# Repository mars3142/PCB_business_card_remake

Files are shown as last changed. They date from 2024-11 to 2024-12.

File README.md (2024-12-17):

# PCB business card - StuckAtPrototype

A custom PCB based "business" card that lets you play a version of Flappy Bird. 

## Youtube Video
A bit of a back-story of how this project came to be.

My Kickstarter failed, so I open sourced it (https://youtu.be/y-lWarLUhfg)

Sub if you like what you see.

## Project Structure
The project consists of
1. Firmware
2. Hardware
3. Mechanical
4. Scripts

These are structured into their own files. I could have used submodules, but decided against it.

### 1. Firmware
Code for the business card. This lives on the ESP32

#### Requirements
- ESP32 IDF version 5.4
- Target set to ESP32-H2
- BLE configured to NIMBLE

### 2. Hardware

#### Schematic
PDF schematic included for your viewing pleasure.
#### PCBs
All the gerber files you'd need to send to a fab house.
#### Kicad
All the files you'd need to expand and work on this further. If you'd like.

### 3. Mechanical

#### Enclosure
All the step files you need to make one of these. Extrusion printer works well for this part.

### 4. Scripts

The script requires the `config.py` file to be modified. You will need to create your own API key at openweather.org

To run the script, simply run `python CardController.py`

#### Requirements
A bunch of pip packages

## What the project could use
1. Cleanup, but thats true for almost anything out there
2. A proper graphics library -- Adafruit, or even LVGL 
3. Scripts that would show stock data. anyone? 

## If you take it further
Let me know if you ever make one of these, I'd love to see it. Seriously, that'd be exciting and inspiring to keep making my projects open source!

## Known issues
1. Switch requires to be shorted due to power consumption at run time
2. GPIO 1 as is does not allow the device to wake up from sleep
3. The LEDs seem to be pulling a lot power even when ESP32 is in deep sleep mode

---
## License
### Apache 2.0 -- i.e. use as you'd like
http://www.apache.org/licenses/LICENSE-2.0

--- 
## Special Thanks
Thanks to Michael Angerer for his open sourced `esp32_ble_ota` project. I used it to get BLE running in this project. His blog post and github repo are a great resource. Check it out. https://github.com/michael-angerer/esp32_ble_ota

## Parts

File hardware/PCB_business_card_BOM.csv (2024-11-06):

Id | Designator | Footprint | Quantity | Designation | Supplier and ref | Notes
1 | LED16,LED107,LED49,LED64,LED59,LED106,LED6,LED3,LED36,LED34,LED15,LED109,LED4,LED74,LED82,LED47,LED28,LED73,LED75,LED20,LED81,LED90,LED19,LED8,LED44,LED58,LED35,LED72,LED17,LED61,LED12,LED63,LED48,LED116,LED29,LED93,LED96,LED102,LED5,LED51,LED18,LED7,LED39,LED53,LED56,LED37,LED95,LED31,LED62,LED42,LED98,LED117,LED43,LED60,LED57,LED45,LED24,LED23,LED79,LED97,LED105,LED27,LED112,LED89,LED25,LED70,LED54,LED50,LED120,LED100,LED68,LED119,LED30,LED66,LED88,LED76,LED80,LED21,LED110,LED11,LED33,LED41,LED94,LED2,LED103,LED78,LED1,LED9,LED38,LED87,LED114,LED115,LED32,LED67,LED10,LED111,LED108,LED104,LED26,LED52,LED69,LED86,LED84,LED22,LED13,LED40,LED14,LED85,LED83,LED101,LED46,LED91,LED55,LED77,LED113,LED118,LED71,LED99,LED92,LED65 | IN-PI15_INL | 120 | IN-PI15TAT5R5G5B | IN-PI15TAT5R5G5B
3 | S4,S2,S3 | SW_PTS810_SJM_250_SMTR_LFS | 3 | SW_PTS810_SJM_250_SMTR_LFS | PTS810 SJM 250 SMTR LFS
4 | C114,C51,C33,C105,C24,C129,C92,C32,C96,C55,C6,C62,C81,C36,C17,C74,C64,C116,C103,C100,C59,C30,C61,C27,C25,C124,C7,C34,C26,C118,C37,C120,C108,C69,C9,C71,C63,C88,C52,C49,C20,C125,C40,C47,C99,C72,C53,C94,C107,C41,C57,C68,C14,C75,C106,C87,C45,C82,C48,C104,C78,C43,C35,C113,C122,C58,C101,C28,C119,C89,C46,C110,C76,C98,C67,C31,C39,C112,C54,C44,C19,C38,C22,C86,C97,C130,C102,C80,C18,C91,C128,C23,C93,C131,C115,C50,C111,C77,C21,C123,C83,C60,C13,C84,C85,C79,C12,C11,C70,C127,C15,C126,C109,C56,C42,C95,C73,C132,C65,C90,C29,C16,C66,C121 | C_0603_1608Metric | 124 | 0.1uF | CC0603KRX7R7BB104
5 | R5,R6 | R_0603_1608Metric | 2 | 5k1 | RMCF0603JT5R10
6 | R16,R17,R28,R27,R11,R10,R19 | R_0603_1608Metric | 7 | 10k | WR06X103 JTL
7 | C2,C135,C10,C133,C3,C1 | C_0603_1608Metric | 6 | 10uF | GRM188R61A106ME69D
8 | U1 | TPS631000DRLR_TEX | 1 | TPS631000DRLR | TPS631000DRLR
9 | D1 | D_0603_1608Metric | 1 | PWLED | 150060RS75000
10 | R14,R20 | R_0603_1608Metric | 2 | 100k | WR06X1003FTL
11 | C8,C117 | C_0603_1608Metric | 2 | 1uF 25V | CC0603KRX5R8BB105
12 | R3 | R_0603_1608Metric | 1 | 75K | ERJ-PB3B7502V
13 | R23 | R_0603_1608Metric | 1 | 0 |  | NOTE: solder jump
14 | D4 | D_0603_1608Metric | 1 | LED | 150060GS75000 | NOTE: might be mixed up with D3
15 | D3 | D_0603_1608Metric | 1 | LED | 150060RS75000 | NOTE: might be mixed up with D4
16 | TH1 | R_0603_1608Metric | 1 | TH 10k | NTCG163JF103HT1
17 | Q3 | SOT-23 | 1 | BSS138 | BSS138
18 | U2 | SON50P300X300X100-11N | 1 | MCP73833 | MCP73833T-AMI/MF
19 | S1 | SW_JS102011SAQN | 1 | JS102011SAQN | JS102011SAQN
20 | C5 | C_0603_1608Metric | 1 | 47uF | GRM188C80E476ME05D
21 | C4 | C_0603_1608Metric | 1 | 22uF | GRM188R60J226MEA0J
22 | R15,R18 | R_0603_1608Metric | 2 | 10K | WR06X103 JTL | NOTE: combine with above
23 | R21,R12,R22 | R_0603_1608Metric | 3 | 470 | ESR03EZPF4700
25 | R7 | R_0603_1608Metric | 1 | 1M | RMCF0603FT1M00
26 | L1 | RES_CIGT252010 | 1 | 1uH | CIGT252010EH1R0MNE
27 | P1 | GCT_USB4105-GF-A | 1 | USB_C_Plug_USB2.0 | USB4105-GF-A
28 | U5 | AP2204 | 1 | AP2204 | AP2205-33W5-7 | NOTE: changed for AP2205
29 | R1 | R_0603_1608Metric | 1 | 806 | RQ73C1J806RBTDF
31 | R2 | R_0603_1608Metric | 1 | 1.43K | RT0603BRE071K43L
32 | R8,R9 | R_0603_1608Metric | 2 | 200 |  | NOTE: change to 470
33 | D5 | D_SMA | 1 | D_Schottky 1A | MBRA210LT3G | NOTE: changed to 2A diode
34 | Q1 | SOT-23-DMG2301 | 1 | Q_PMOS_SGD | DMG2301L-7
35 | C134 | C_0603_1608Metric | 1 | 2.2uF | CL10A225KO8NNNC
36 | J3 | JST_PH_S2B-PH-SM4-TB_1x02-1MP_P2.00mm_Horizontal | 1 | JST 2.0 BATT | S2B-PH-SM4-TB
37 | R13 | R_0603_1608Metric | 1 | 91 | CR0603-FX-91R0ELF
38 | U3 | MODULE_ESP32-H2-MINI-1-H2 | 1 | ESP32-H2-MINI-1 | ESP32-H2-MINI-1
39 | U4 | A3908 | 1 | A3908 | A3908EEETR-T
40 | D2 | D_SOD-523 | 1 | TPD1E10B06DPYR | TPD1E10B06DYAR
41 | R4 | R_0603_1608Metric | 1 | 5K1 | RMCF0603JT5R10 | NOTE: combine with above

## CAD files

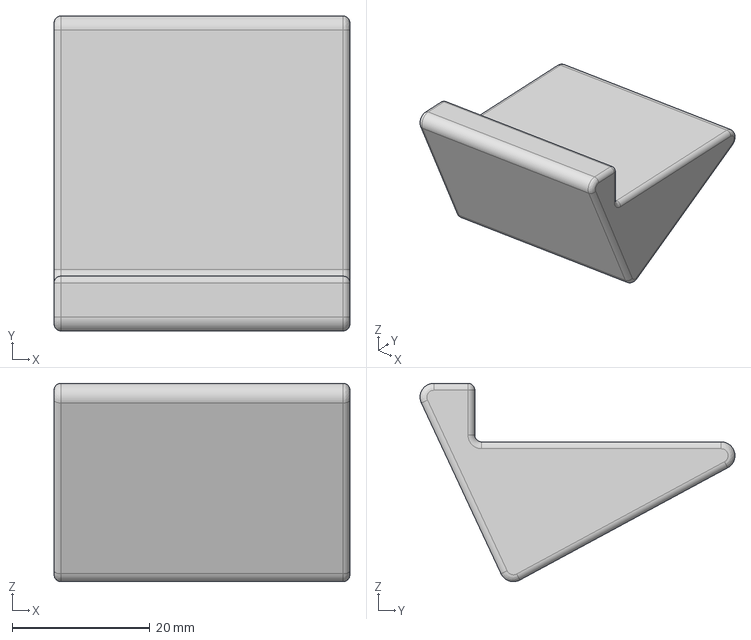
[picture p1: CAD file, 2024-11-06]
mechanical/PCB business card enclosure stand.step
43.0 x 45.8 x 28.8 mm

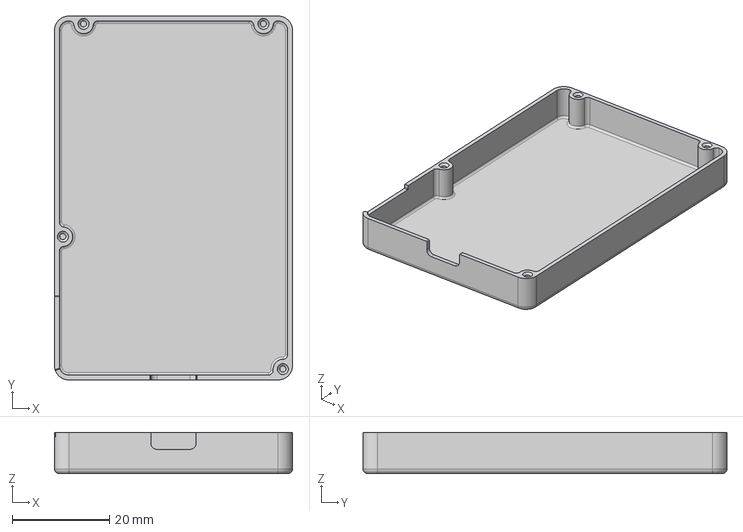
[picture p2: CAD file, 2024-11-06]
mechanical/PCB business card enclosure.step
49.0 x 74.9 x 8.50 mm

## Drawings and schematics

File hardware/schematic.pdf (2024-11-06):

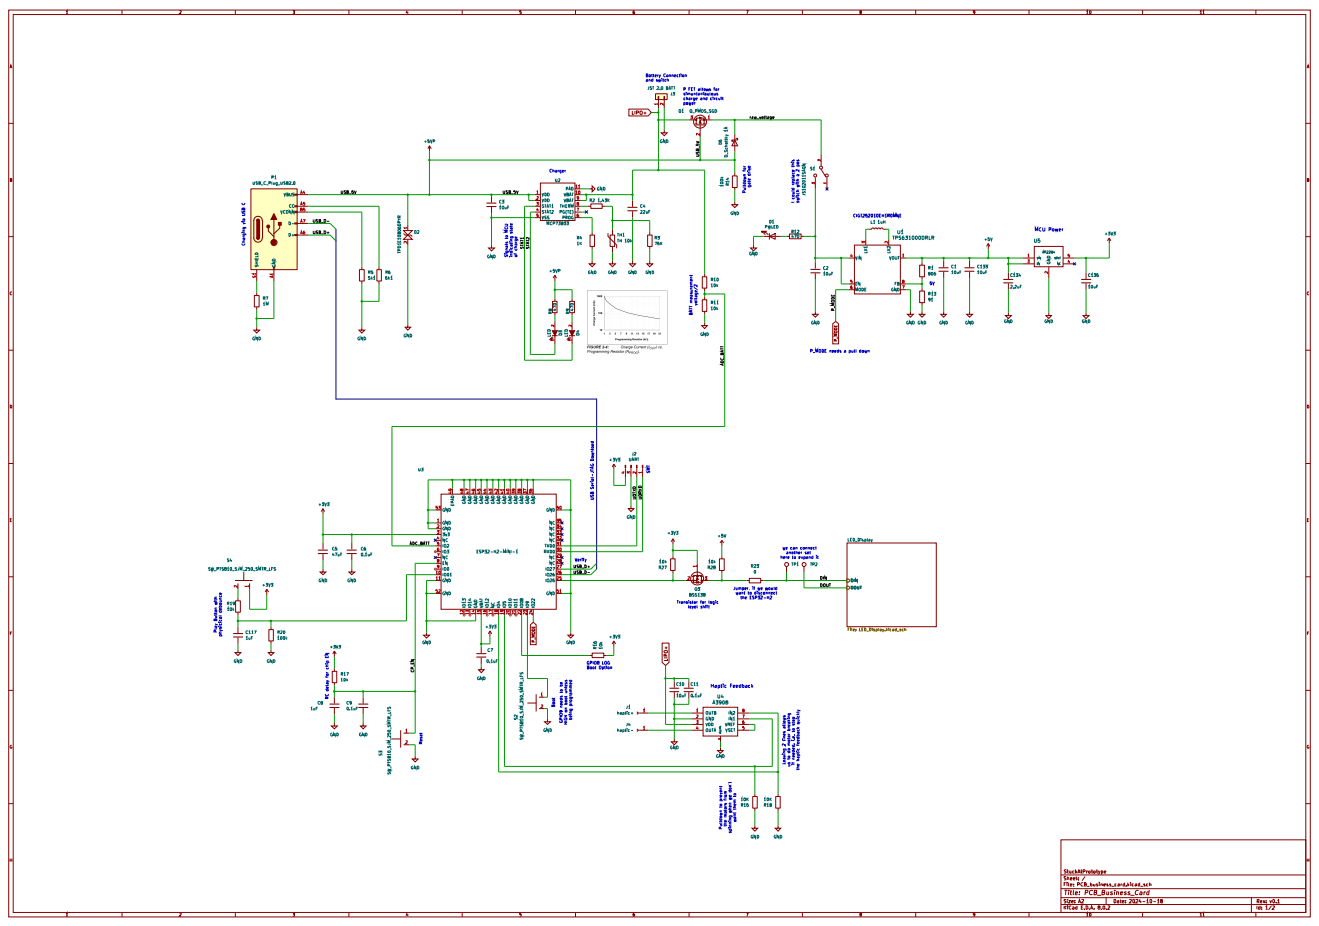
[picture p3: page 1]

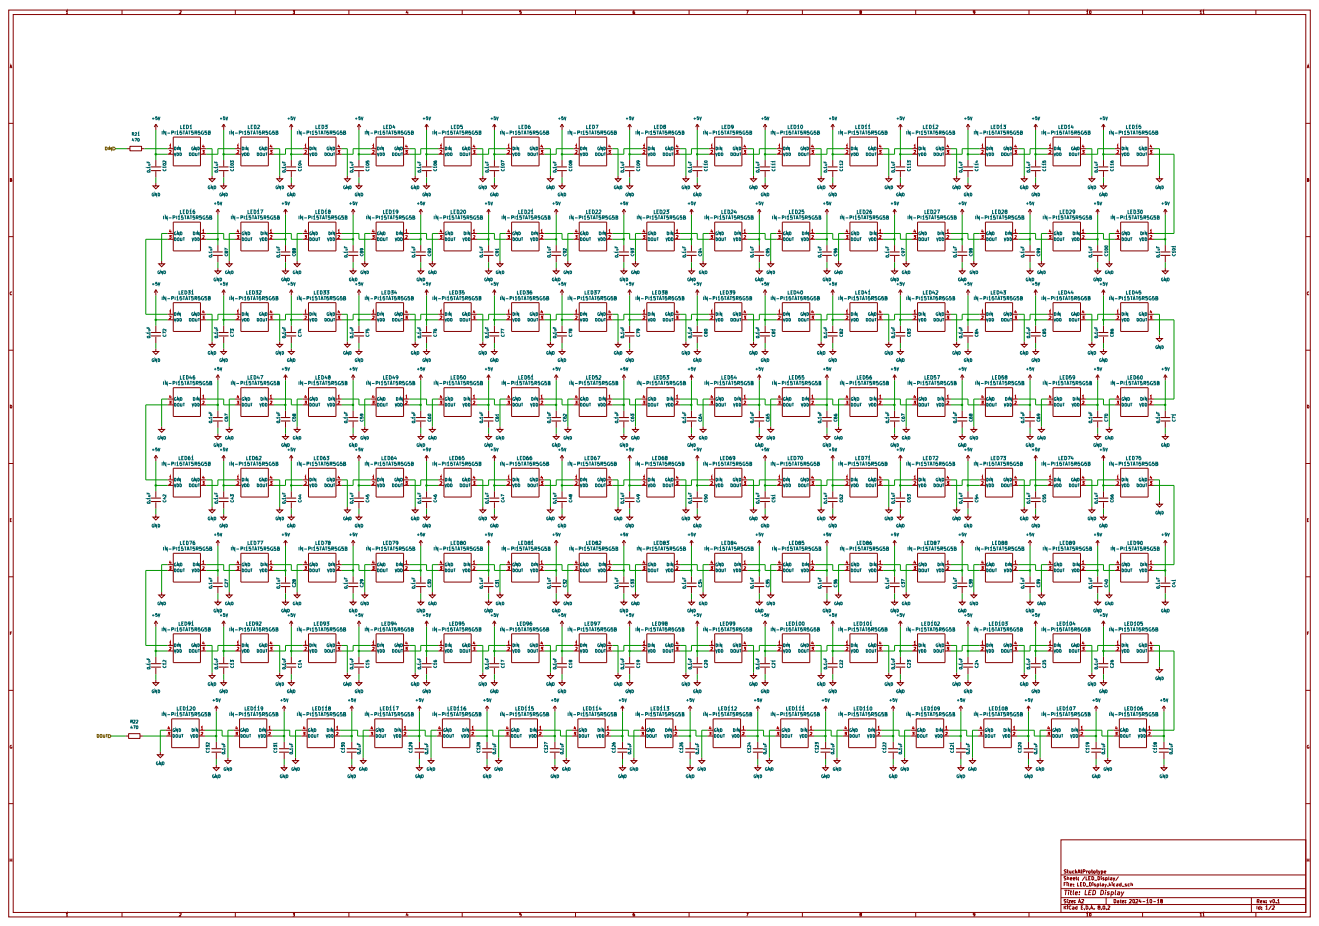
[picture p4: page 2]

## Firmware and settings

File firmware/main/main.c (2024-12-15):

// main.c

#include <stdio.h>
#include <inttypes.h>
#include "sdkconfig.h"
#include "freertos/FreeRTOS.h"
#include "freertos/task.h"
#include "freertos/queue.h"
#include "freertos/semphr.h"
#include "esp_chip_info.h"
#include "esp_flash.h"
#include "esp_system.h"
#include "esp_cpu.h"
#include "esp_log.h"
#include "driver/ledc.h"
#include "driver/gpio.h"
#include "esp_sleep.h"

// BLE
#include "gap.h"
#include "gatt_svr.h"
#include "nvs_flash.h"
#include "esp_bt.h"

// user generated
#include "ws2812_control.h"
#include "motor.h"
#include "gpio_interrupt.h"
#include "display_helpers.h"
#include "game.h"

// random
#include "esp_random.h"

// usb drivers
#include "driver/usb_serial_jtag.h"
#include "esp_vfs_dev.h"
#include "driver/usb_serial_jtag_vfs.h"

static const char *TAG = "main";

#define RED   0x001000
#define GREEN 0x100000
#define BLUE  0x000010

#include <stdint.h>
#include <math.h>

struct led_state new_state;

SemaphoreHandle_t haptic_mutex;

#define LONG_PRESS_DURATION 2000 // 2 seconds in milliseconds

// expand this to include more "apps" -- think flash light, etc
enum app_states {
    APP_SPLASH_SCREEN,
    APP_GAME,
    APP_BLUETOOTH_CONTROL,
    APP_OFF,
    APP_MAX_STATES // This is to keep track of the number of states
};

// Current state of the application
enum app_states current_state = APP_SPLASH_SCREEN;

// Last state of the button
bool last_button_state = false;
uint32_t button_press_time = 0;
bool button_press_detected = false;


float get_next_hue(void) {
    static float hue = 0.0f;

    // Increment hue for next call
    hue += 0.01f; // Adjust this value to control the speed of the color change
    if (hue >= 1.0f) hue = 0.0f;

    return hue;
}

QueueHandle_t gpio_intr_evt_queue = NULL;
void gpio_interrupt_task(void *pvParameters)
{
    uint32_t io_num;
    for(;;) {
        if(xQueueReceive(gpio_intr_evt_queue, &io_num, portMAX_DELAY)) {
            ESP_LOGD(TAG, "GPIO[%lu] interrupt occurred!\n", io_num);
            if (gpio_get_level(io_num) == 1) {

                // this could be wrapped up into its own thing instead of dealing with semaphores
                if (xSemaphoreTake(haptic_mutex, portMAX_DELAY) == pdTRUE) {

                    MotorUpdate update_a = {0, 100, 1};
                    xQueueSend(motor_queue[0], &update_a, 0);

                    vTaskDelay(30 / portTICK_PERIOD_MS);  // Delay

                    // turn off the motor
                    update_a.speed_percent = 0;
                    xQueueSend(motor_queue[0], &update_a, 0);
                    xSemaphoreGive(haptic_mutex);
                }
            }
        }
    }
}


// count how many digits in a number
int count_digits(int number) {
    if (number == 0) return 1;
    int count = 0;
    while (number != 0) {
        number /= 10;
        count++;
    }

    return count;
}


uint32_t game_delay_reset = 0;
uint32_t game_over_haptic = 0;

void game_loop(void){

    MotorUpdate update_a = {0, 100, 1};

    // if the game is over, reset if user presses the button
    if(game_get_game_over() == 1){

        // let the user see what happened for 20 frames
        if(game_delay_reset > 20){
            // get the game score
            int score = (int)game_get_score();
            if(score > 9999)
                score = 9999; // display limit

            // write the display buffer to the new state buffer
            display_clear();

            // determine the center of our string
            int start_x = (15 - (count_digits(score) * 4 - 1)) / 2;

            // write the score to screen
            display_number(score, start_x,2);
        }

        if(game_delay_reset > 0 && game_delay_reset < 30 && game_over_haptic == 0){
            if (xSemaphoreTake(haptic_mutex, portMAX_DELAY) == pdTRUE) {
                update_a.speed_percent = 100;
                xQueueSend(motor_queue[0], &update_a, 0);
                game_over_haptic = 1;
            }

        } else if (game_delay_reset > 30 && game_over_haptic == 1){
            update_a.speed_percent = 0;
            xQueueSend(motor_queue[0], &update_a, 0);
            game_over_haptic = 0;
            xSemaphoreGive(haptic_mutex);
        }

        if(game_delay_reset > 30){

            // wait for a button press to restart
            if (gpio_get_level(INTERRUPT_PIN) == 1) {
                game_reset();
                game_delay_reset = 0;
            }
        }

        // delay reset counter
        game_delay_reset++;

    } else{
        // run the game logic
        game_run();

        // write the display buffer
        game_compile_buffer(display_buffer);

    }
}

uint8_t short_press_detect(void){
    uint8_t short_press = 0;

    if(gpio_get_level(INTERRUPT_PIN) == 1){
        short_press = 1;
    }

    return short_press;
}


uint8_t button_press_detect(uint32_t press_duration) {
    // Read the current state of the button
    bool current_button_state = gpio_get_level(INTERRUPT_PIN);

    uint8_t press = 0;

    // Check for button press start
    if (current_button_state && !last_button_state) {
        button_press_time = xTaskGetTickCount() * portTICK_PERIOD_MS;
        button_press_detected = false; // Reset detection flag
    } else if (current_button_state && last_button_state) {
        uint32_t elapsed_time = xTaskGetTickCount() * portTICK_PERIOD_MS - button_press_time;
        if (elapsed_time > press_duration && !button_press_detected) {
            press = 1;
            button_press_detected = true; // Set detection flag
        }
    } else if (!current_button_state && last_button_state) {
        // Button released, reset the button press time and detection flag
        button_press_time = 0;
        button_press_detected = false;
    }

    last_button_state = current_button_state;

    return press;
}

// this is the main logic loop
void main_loop(void *pvParameters){
    TickType_t xLastWakeTime = xTaskGetTickCount();
    const TickType_t xFrequency = pdMS_TO_TICKS(20); // For 50 Hz (1000 ms / 50 = 20 ms)

    while(1){

        // a delay that allows us to precisely run at a specified frequency
        vTaskDelayUntil(&xLastWakeTime, xFrequency);

        // Run the current application state
        switch (current_state) {
            case APP_SPLASH_SCREEN:
                // Code to run the splash screen app
                float hue = get_next_hue();
                uint32_t next_color = hsv_to_rgb(hue, 1.0f, 0.5f);
                for(int i = 0; i < 8; i++){
                    for(int b = 0; b < 15; b++)
                        display_buffer[i][b] = next_color;
                }

                if(button_press_detect(100) == 1){
                    // Transition to the next state
                    current_state = (current_state + 1) % APP_MAX_STATES;
                }

                break;
            case APP_GAME:
                // Code to run the game app
                game_loop();

                if(button_press_detect(1000) == 1){
                    // Transition to the next state
                    current_state = (current_state + 1) % APP_MAX_STATES;

                }

                break;
            case APP_BLUETOOTH_CONTROL:
                // Code to run the Bluetooth control app
                // write the bt buffer to the main display buffer

                // check if there is an active connection
                // if there is an active connection, write the buffer
                // else write the bt logo
                if(gatt_get_num_pkgs_recieved() > 0) {
                    for (int i = 0; i < 8; i++) {
                        for (int b = 0; b < 15; b++) {
                            display_buffer[i][b] = display_bt_buffer[i][b];
                        }
                    }
                } else {
                    display_draw_bt_logo();
                    // Write a string to the display
//                    display_write_string("BLE", 0, 0);
                }

                if(button_press_detect(1000) == 1) {
                    // Transition to the next state
                    current_state = (current_state + 1) % APP_MAX_STATES;
                }
                break;
            case APP_OFF:

                // clear the screen and set low power mode on the esp32
                // Enable wakeup on GPIO 1 (high level)
                esp_sleep_enable_ext1_wakeup(1ULL << INTERRUPT_PIN, ESP_EXT1_WAKEUP_ANY_HIGH);

                display_clear();
                display_write_buffer(&new_state);
                ws2812_write_leds(new_state);

                vTaskDelay(pdMS_TO_TICKS(1000));

                // Enter deep sleep
                esp_deep_sleep_start();
                break;

            default:
                // Handle invalid state (should not occur)
                break;
        }


        display_write_buffer(&new_state);
        ws2812_write_leds(new_state);

    }

}

void app_main(void)
{
    usb_serial_jtag_driver_config_t usb_serial_jtag_config = USB_SERIAL_JTAG_DRIVER_CONFIG_DEFAULT();
    usb_serial_jtag_driver_install(&usb_serial_jtag_config);

    usb_serial_jtag_vfs_use_driver();

    // wait a little bit for the drivers to kick in
    vTaskDelay(1000 / portTICK_PERIOD_MS);


    ESP_LOGI(TAG, "starting up");

    haptic_mutex = xSemaphoreCreateMutex();

    // init led driver
    ws2812_control_init();
    ESP_LOGI(TAG, "ws driver initialized");

    // BLE Setup -------------------
    nimble_port_init();
    ble_hs_cfg.sync_cb = sync_cb;
    ble_hs_cfg.reset_cb = reset_cb;
    gatt_svr_init();
    ble_svc_gap_device_name_set(device_name);
    nimble_port_freertos_init(host_task);

    // initilize interrupt and input on IO1
    configure_gpio_interrupt();
    gpio_intr_evt_queue = gpio_interrupt_get_evt_queue();
    xTaskCreate(gpio_interrupt_task, "gpio_interrupt_task", 2048, NULL, 2, NULL);

    // haptic feedback
    motor_init();

    // initialize the task for game logic loop
    xTaskCreate(main_loop, "main_loop", 4096,
                NULL, 0, NULL);



    while (1) {

        vTaskDelay(1000 / portTICK_PERIOD_MS);  // Delay

    }
}

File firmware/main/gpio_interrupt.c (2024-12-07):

#include "gpio_interrupt.h"
#include <stdio.h>
#include "freertos/task.h"
#include "driver/gpio.h"

#define GPIO_QUEUE_LENGTH 10
#define GPIO_QUEUE_ITEM_SIZE sizeof(uint32_t)
#define DEBOUNCE_TIME_MS 30

QueueHandle_t gpio_evt_queue = NULL;

QueueHandle_t gpio_interrupt_get_evt_queue(void){
    return gpio_evt_queue;
}

static void IRAM_ATTR gpio_isr_handler(void* arg)
{
    static uint32_t last_interrupt_time = 0;
    uint32_t interrupt_time = xTaskGetTickCountFromISR();
    uint32_t gpio_num = (uint32_t) arg;

    // Check if it's a rising edge
    if (gpio_get_level(gpio_num) == 1) {
        // Debounce mechanism
        if (interrupt_time - last_interrupt_time > pdMS_TO_TICKS(DEBOUNCE_TIME_MS)) {
            xQueueSendFromISR(gpio_evt_queue, &gpio_num, NULL);
            last_interrupt_time = interrupt_time;
        }
    }
}

void configure_gpio_interrupt(void)
{
    // Create a queue to handle GPIO event from ISR
    gpio_evt_queue = xQueueCreate(GPIO_QUEUE_LENGTH, GPIO_QUEUE_ITEM_SIZE);

    // Configure the GPIO pin
    gpio_config_t io_conf = {};
    io_conf.intr_type = GPIO_INTR_POSEDGE;  // Interrupt on falling edge only
    io_conf.pin_bit_mask = (1ULL << INTERRUPT_PIN);  // Bit mask of the pin
    io_conf.mode = GPIO_MODE_INPUT;  // Set as input
    io_conf.pull_up_en = GPIO_PULLUP_DISABLE;  // pull-up resistor
    io_conf.pull_down_en = GPIO_PULLUP_DISABLE;  // Disable pull-down resistor
    gpio_config(&io_conf);

    // Install GPIO ISR service
    gpio_install_isr_service(0);

    // Attach the interrupt service routine
    gpio_isr_handler_add(INTERRUPT_PIN, gpio_isr_handler, (void*) INTERRUPT_PIN);

    printf("GPIO %d configured for interrupt on falling edge only with pull-up enabled and %d ms debounce\n", INTERRUPT_PIN, DEBOUNCE_TIME_MS);
}

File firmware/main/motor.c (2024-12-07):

#include "motor.h"
#include <stdio.h>
#include "esp_log.h"

#define MOTOR_HAPTIC_FWD_GPIO        4
#define MOTOR_HAPTIC_BWD_GPIO        5

#define LEDC_TIMER              LEDC_TIMER_0
#define LEDC_MODE               LEDC_LOW_SPEED_MODE
#define LEDC_DUTY_RES           LEDC_TIMER_10_BIT // Set duty resolution to 13 bits
#define LEDC_FREQUENCY          (15000) // Frequency in Hertz. Set frequency at 15 kHz

QueueHandle_t motor_queue[2];
SemaphoreHandle_t motor_start_semaphore;

void motor_init(void){
    // initialize haptic feedback
    ledc_timer_config_t ledc_timer = {
            .speed_mode       = LEDC_MODE,
            .timer_num        = LEDC_TIMER,
            .duty_resolution  = LEDC_DUTY_RES,
            .freq_hz          = LEDC_FREQUENCY,
            .clk_cfg          = LEDC_AUTO_CLK
    };
    esp_err_t err = ledc_timer_config(&ledc_timer);
    if (err != ESP_OK) {
        printf("LEDC Timer Config failed: %s\n", esp_err_to_name(err));
        return;
    }

    configure_motor_pwm(MOTOR_HAPTIC_FWD_GPIO, LEDC_CHANNEL_0);
    configure_motor_pwm(MOTOR_HAPTIC_BWD_GPIO, LEDC_CHANNEL_1);

    // Create motor queue
    motor_queue[0] = xQueueCreate(MOTOR_QUEUE_SIZE, sizeof(MotorUpdate));
    if (motor_queue[0] == NULL) {
        printf("Failed to create motor queue\n");
        return;
    }

    xTaskCreate(motor_task, "motor_task_haptic", 2048, (void *)0, 1, NULL);

}

void configure_motor_pwm(int gpio, ledc_channel_t channel)
{
    ledc_channel_config_t ledc_channel = {
            .speed_mode     = LEDC_LOW_SPEED_MODE,
            .channel        = channel,
            .timer_sel      = LEDC_TIMER_0,
            .intr_type      = LEDC_INTR_DISABLE,
            .gpio_num       = gpio,
            .duty           = 0,
            .hpoint         = 0
    };
    esp_err_t err = ledc_channel_config(&ledc_channel);
    if (err != ESP_OK) {
        ESP_LOGE("motor","LEDC Channel Config failed for GPIO %d: %s", gpio, esp_err_to_name(err));
    }
}

void set_motor_speed(int motor_index, int speed_percent, bool direction)
{
    if (motor_index < 0 || motor_index >= NUM_MOTORS) {
        ESP_LOGE("motor","Invalid motor index");
        return;
    }

    // Ensure speed_percent is between MIN_SPEED_PERCENT and 100
    speed_percent = (speed_percent < MIN_SPEED_PERCENT) ? 0 : (speed_percent > 100) ? 100 : speed_percent;

    // Map MIN_SPEED_PERCENT-100 to MIN_DUTY-MAX_DUTY
    int duty;
    if (speed_percent == 0) {
        duty = 0;
    } else {
        int min_duty = (MIN_SPEED_PERCENT * MAX_DUTY) / 100;
        duty = min_duty + ((speed_percent - MIN_SPEED_PERCENT) * (MAX_DUTY - min_duty)) / (100 - MIN_SPEED_PERCENT);
    }

    ledc_channel_t fwd_channel = (ledc_channel_t)(motor_index * 2);
    ledc_channel_t bwd_channel = (ledc_channel_t)(motor_index * 2 + 1);

    ledc_set_duty(LEDC_LOW_SPEED_MODE, fwd_channel, direction ? duty : 0);
    ledc_set_duty(LEDC_LOW_SPEED_MODE, bwd_channel, direction ? 0 : duty);
    ledc_update_duty(LEDC_LOW_SPEED_MODE, fwd_channel);
    ledc_update_duty(LEDC_LOW_SPEED_MODE, bwd_channel);

    ESP_LOGD("motor","Motor %d set to speed %d%% (duty %d), direction %s",
           motor_index, speed_percent, duty, direction ? "FORWARD" : "BACKWARD");
}

void soft_start_motor(int motor_index, int target_speed, bool target_direction)
{
    static int current_speed[NUM_MOTORS] = {0};
    static bool current_direction[NUM_MOTORS] = {true};

    int start_speed = current_speed[motor_index];
    bool start_direction = current_direction[motor_index];

    // If direction is changing, first slow down to 0
    if (start_direction != target_direction && start_speed > 0) {
        ESP_LOGD("motor","slow stopping motor %i", motor_index);
        for (int speed = start_speed; speed >= MIN_SPEED_PERCENT; speed--) {
            set_motor_speed(motor_index, speed, start_direction);
            vTaskDelay(SOFT_START_DELAY_MS / portTICK_PERIOD_MS);
        }
        set_motor_speed(motor_index, 0, start_direction);
        start_speed = 0;
    }

    // Now ramp up to target speed in the correct direction
    if (target_speed > 0) {
        ESP_LOGD("motor","ramping up motor %i", motor_index);
        if (start_speed == 0) {
            ESP_LOGD("motor","initial speed was 0 %i", motor_index);
            set_motor_speed(motor_index, MIN_SPEED_PERCENT, target_direction);
            vTaskDelay(SOFT_START_DELAY_MS * 2 / portTICK_PERIOD_MS);  // Longer delay for initial start
            start_speed = MIN_SPEED_PERCENT;
        }

        int step = (target_speed > start_speed) ? 1 : -1;
        for (int speed = start_speed; speed != target_speed; speed += step) {
            set_motor_speed(motor_index, speed, target_direction);
            vTaskDelay(SOFT_START_DELAY_MS / portTICK_PERIOD_MS);
        }
    } else {
        ESP_LOGD("motor","direct set on motor %i", motor_index);
        set_motor_speed(motor_index, 0, target_direction);
    }

    // Ensure we reach exactly the target speed
    set_motor_speed(motor_index, target_speed, target_direction);

    // Update current speed and direction
    current_speed[motor_index] = target_speed;
    current_direction[motor_index] = target_direction;
    ESP_LOGD("motor","done with motor %i", motor_index);

}

void motor_task(void *pvParameters)
{
    int motor_index = (int)pvParameters;
    MotorUpdate update;
    while (1) {
        if (xQueueReceive(motor_queue[0], &update, pdMS_TO_TICKS(10)) == pdTRUE) {
            ESP_LOGD("Motor", "motor index %i speed %i direction %i", update.motor_index, update.speed_percent,
                     update.direction);
            set_motor_speed(update.motor_index, update.speed_percent, update.direction);
        }
    }
}

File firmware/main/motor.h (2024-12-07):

#ifndef MOTOR_H
#define MOTOR_H

#include "freertos/FreeRTOS.h"
#include "freertos/task.h"
#include "freertos/queue.h"
#include "freertos/semphr.h"
#include "driver/ledc.h"

#define NUM_MOTORS              1
#define MIN_SPEED_PERCENT       15  // Minimum speed percentage
#define MAX_DUTY                ((1 << LEDC_TIMER_10_BIT) - 1)  // Max duty cycle for 10-bit resolution
#define MOTOR_QUEUE_SIZE        20
#define SOFT_START_DELAY_MS     30  // Adjust this value to change the softness of the start

// Motor speed update structure
typedef struct {
    int motor_index;
    int speed_percent;
    bool direction;
} MotorUpdate;

void motor_init(void);
void configure_motor_pwm(int gpio, ledc_channel_t channel);
void set_motor_speed(int motor_index, int speed_percent, bool direction);
void soft_start_motor(int motor_index, int target_speed, bool target_direction);
void motor_task(void *pvParameters);

extern QueueHandle_t motor_queue[2];
extern SemaphoreHandle_t motor_start_semaphore;

#endif // MOTOR_H

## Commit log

2024-10-31 Add files via upload
    This is the Art for PCB business card first push
2024-11-06 initial hardware, firmware and mechanical files
    [LED_Display.kicad_sch, PCB business card enclosure stand.step, PCB business card enclosure.step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]
2024-12-09 card controller now displays temperature while scrolling independently
2024-12-15 changing input pin number. this allows the device to wake up from deep sleep with the main button. requires a slight PCB change
